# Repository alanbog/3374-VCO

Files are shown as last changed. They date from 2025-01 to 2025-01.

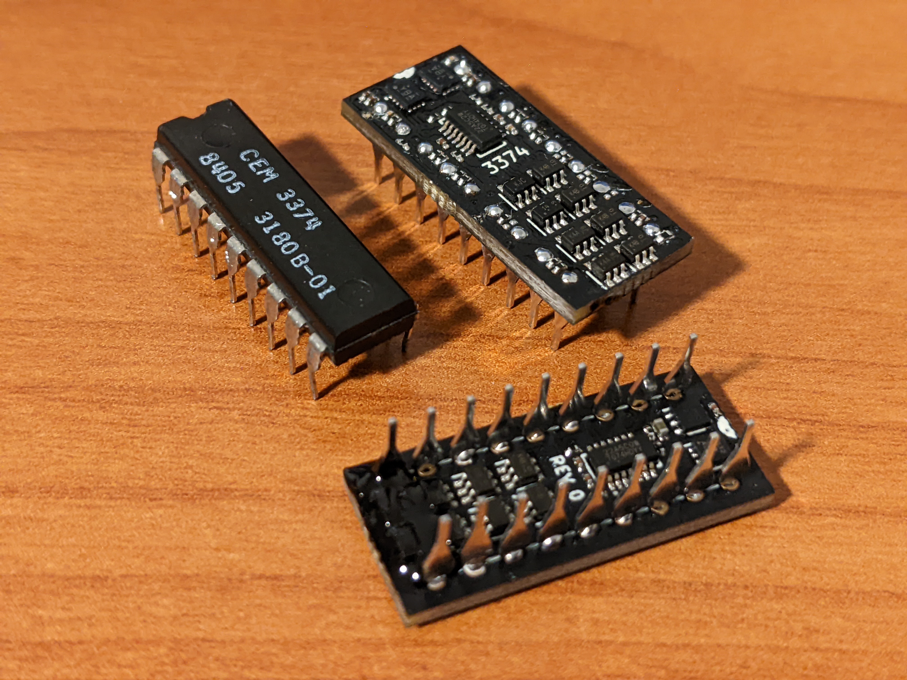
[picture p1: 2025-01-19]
3374 VCO.jpg

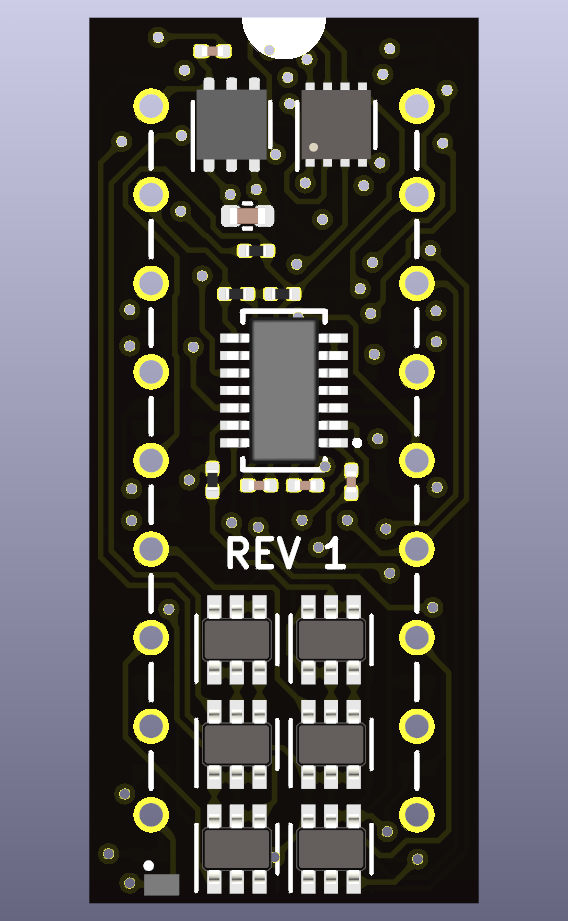
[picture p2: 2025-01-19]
Mfg Files/Drawing/Bot_3D.png

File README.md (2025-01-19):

# 3374-VCO

This repository contains a circuit designed to be a clone of the CEM 3374 VCO IC used in analog synthesizers from the early 1980s such as:

* Fender Chroma Polaris
* Oberheim Matrix 12
* Oberheim Xpander
* Akai VX600.

It is designed to operate with 12V for Vcc and -5V or -6V for Vee, which is what all of the synthesizers listed above use for supply voltages. The circuit contains two oscillator channels with triangle and sawtooth wave outputs. Triangle wave outputs have an amplitude of 1/3 Vcc, and sawtooth wave outputs have an amplitude of 2/3 Vcc. Synthesizers using the CEM 3374 that generate square/pulse waves do so with external comparator circuits. 

Channel A sync is implemented. Channel B sync is not implemented, but this feature was rarely used on the CEM 3374 (None of the synthesizers listed above use it). 

A thermistor circuit is used to provede a temperature compensated reference voltage. Typically, this voltage is used as a reference for the DAC that outputs the voltage that controls the frequency of the oscillators.

This was tested on a Chroma Polaris. It should work in all of the other synthesizers listed above, but it hasn't been tested. 

For Rev 1, the oscillator circuit was updated to fix an issue with Oberheim Synthesizers being out of tune at lower notes (although this fix hasn't yet been tested on an Oberheim synthesizer).

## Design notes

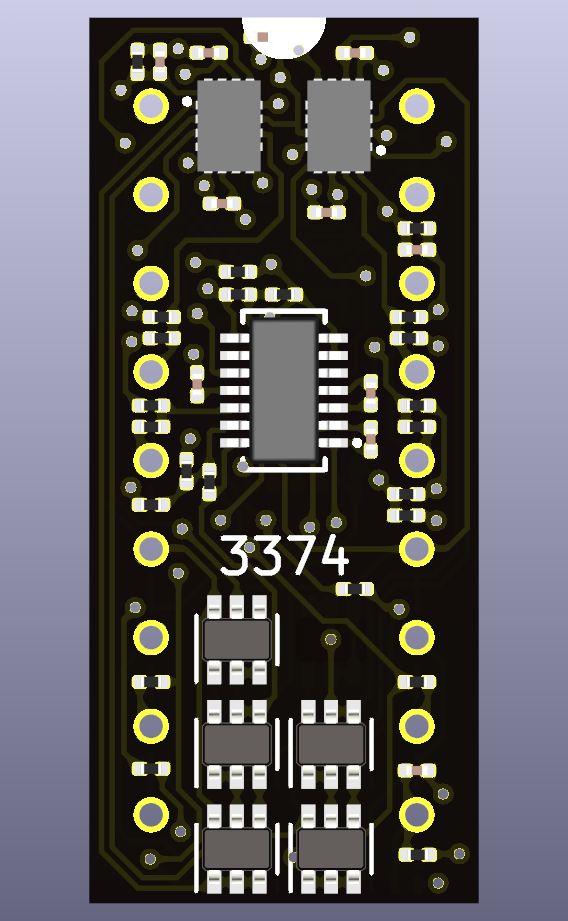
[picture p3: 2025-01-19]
Mfg Files/Drawing/Top_3D.png

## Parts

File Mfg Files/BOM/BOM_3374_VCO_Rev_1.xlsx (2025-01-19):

3374 VCO Rev 1 BOM (12-Dec-2024)
# | Reference | Qty | Value | DNP | Description | Mfg | Mfg PN | Distributor | Distributor PN | Package | Type | Substitute part okay?
1 | C1,C2,C3,C5,C6,C8,C9,C11,C12,C15,C16 | 11 | 100n |  | Capacitor, 100nF, 10%, 25V, X5R | Walsin | 0201X104K250CT | LCSC | C880779 | 201 | SMD | Yes
2 | C4,C7,C10,C14 | 4 | 680p |  | Capacitor, 680pF, 10%, 25V, X7R | Murata | GRM033R71E681KA01D | LCSC | C161490 | 201 | SMD | Yes
3 | C13 | 1 | 2.2u |  | Capacitor, 2.2uF, 10%, 25V, X5R | Murata | GRM155R61E225KE11D | LCSC | C385032 | 402 | SMD | Yes
4 | J1,J2 | 2 | FLIP PINS | DNP | Flip Pins, 9-pin | Fliptronics | FLIP-PINS-09 |  |  | FLIP-PINS-09 | DNP
5 | Q1 | 1 | MUN5314DW1 |  | Transistor, Dual Complementary Prebiased, Rb=10k, Rbe=47k | LRC | LMUN5314DW1T1G | LCSC | C417318 | SC-88 | SMD | No
6 | Q2,Q4,Q7,Q9,Q10,Q11 | 6 | DMMT3904W |  | Transistor, Dual Matched NPN | Diodes Inc | DMMT3904W-7-F | LCSC | C155305 | SC-88 | SMD | No
7 | Q3,Q5,Q6,Q8 | 4 | DMMT3906W |  | Transistor, Dual Matched PNP | Diodes Inc | DMMT3906W-7-F | LCSC | C151567 | SC-88 | SMD | No
8 | R1,R2,R20,R21 | 4 | 432K |  | Resistor, 432k Ohm, 1%, 0.05W | Walsin | WR02X4323FAL | LCSC | C367623 | 201 | SMD | Yes
9 | R3,R24 | 2 | 365 |  | Resistor, 365 Ohm, 1%, 0.05W | Uniroyal | 0201WMF3650TEE | LCSC | C423558 | 201 | SMD | Yes
10 | R4,R5,R6,R9,R10,R11,R12,R13,R17,R18,R19,R22,R25,R26 | 14 | 10k |  | Resistor, 10k Ohm, 1%, 0.05W | Uniroyal | 0201WMF1002TEE | LCSC | C473048 | 201 | SMD | Yes
11 | R7,R8,R14,R16 | 4 | 4.99k |  | Resistor, 4.99k Ohm, 1%, 0.05W | Uniroyal | 0201WMF4991TEE | LCSC | C473528 | 201 | SMD | Yes
12 | R15,R27 | 2 | 3.32k |  | Resistor, 3.32k Ohm, 1%, 0.05W | Uniroyal | 0201WMF3321TEE | LCSC | C474121 | 201 | SMD | Yes
13 | R23 | 1 | 11.8k |  | Resistor, 11.8k Ohm, 1%, 0.05W | Yageo | AC0201FR-0711K8L | LCSC | C910595 | 201 | SMD | Yes
14 | U1,U2 | 2 | DG4053E |  | Triple SPDT CMOS Analog Switch | Vishay | DG4053EEN-T1-GE4 | Mouser | 78-DG4053EEN-T1-GE4 | 16-miniQFN | SMD | No
15 | U3,U6 | 2 | TL074H |  | IC, Quad Op Amp | Texas Instruments | TL074HIDYYR | Mouser | 595-TL074HIDYYR | 14-SOT-23-THIN | SMD | No
16 | U4 | 1 | AP7370-50FDC |  | IC, LDO, 5V | Diodes Inc | AP7370-50FDC-7 | Mouser | 621-AP7370-50FDC-7 | 6-UDFN | SMD | No
17 | U5 | 1 | TLV9032 |  | IC, Dual Comparator | Texas Instruments | TLV9032DSGR | Mouser | 595-TLV9032DSGR | 8-WSON | SMD | No
18 | U7 | 1 | TMP6131DECR |  | IC, 10k PTC Thermistor | Texas Instruments | TMP6131DECR | LCSC | C2870682 | 2-X1SON | SMD | No
 | Notes:
 | DNP = Do Not Populate.
 | The distributor indicated in the BOM is a suggestion. Any authorized distibutor may be used.

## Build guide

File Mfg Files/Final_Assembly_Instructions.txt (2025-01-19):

These are instructions to turn the PCB assemblies into the final product.

1.  If the PCBAs are panelized, depanelize them, and sand any remaining mouse bites or rough edges.

2.  Solder the Flip-Pins. I recommend using 20-pin Flip-Pins. Two sets of 20-pin Flip-Pins can be used for every two boards.
    Insert the Flip-Pins in the bottom of the board. Make sure that the plastic aligner does not overlap the thermistor (U7). 
    Follow instructions here:
    http://oshchip.org/products/Soldering_Flip-Pins.html
    Archived: https://web.archive.org/web/20231003143201/http://oshchip.org/products/Soldering_Flip-Pins.html
    I found that it was best to use a flux pen and thin solder (0.015" diameter).

    Note: It looks like flip pins have been discontinued, so I have been using TE Connectivity 1544210-2 as an alternative. It requires some cutting and bending to get it in the right shape. 

3.  Clean flux off of the boards. I used isopropyl alcohol and an ESD-safe brush. 

4.  Add a blob of MG Chemicals 8349TFM that completely encapsulates U7, Q14, and Q15. These components are on the bottom of the board opposite from the pin 1 marking. Let cure for at least 16 hours.

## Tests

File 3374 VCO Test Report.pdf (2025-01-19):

# 3374 VCO Test Report

Alan Boguslawski

Rev 1

18-Jan-25

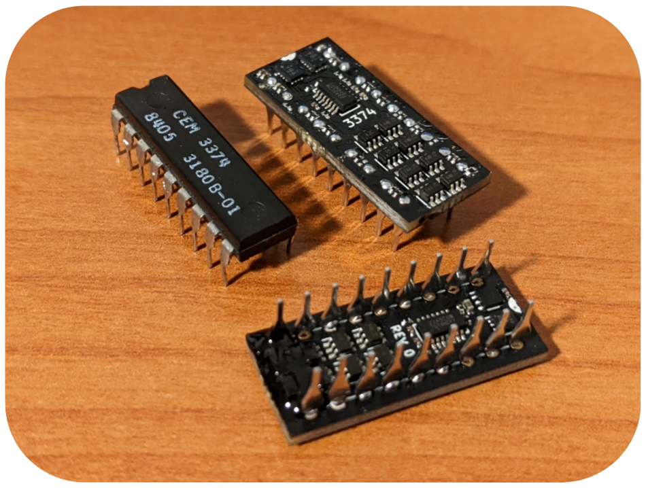
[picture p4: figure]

3374 VCO Test Report | 2

### 1. Background

The purpose of these tests is to verify the functionality of the 3374 VCO clone PCB and to compare the performance to an original CEM 3374 IC. All tests were conducted using a Fender Chroma Polaris running firmware version 8, but the performance characteristics should be similar for other synthesizers using the CEM 3374. The Chroma Polaris supplies the 3374 with 12V and -5V. The Oberheim Matrix 12 and Xpander use the same supply voltages, so performance is expected to be the same. The Akai VX600 also has a 12V positive supply, but the negative supply is -6V (which is unlikely to affect performance).

Revision 1 of this board has modified oscillators, so tests relating to the frequency or wave shape have been retested.

### 2. Frequency vs Voltage

Revision Tested: 1

The frequency and voltage was measured for both oscillators in a CEM 3374 and a clone at increments of one octave. The voltage was measured at the output of the DAC before the voltage divider going to the VCO’s input. The actual voltage at the VCO’s input will be around 1/28th of this voltage. The results are plotted below with a logarithmic vertical axis. Synthesizers using these VCOs use digital calibration, so it is not necessary for the curve to be exactly the same, but it should be close.

3374 VCO Test Report | 3

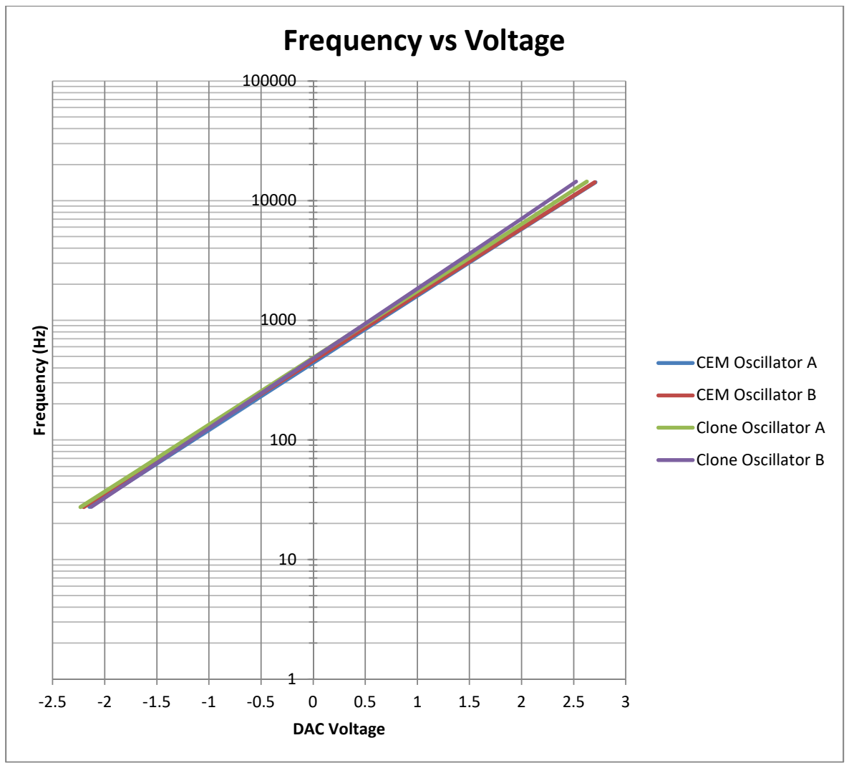
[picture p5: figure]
3 Frequency ⁽Hz⁾; DAC Voltage; Frequency vs Voltage; CEM Oscillator A; CEM Oscillator B; Clone Oscillator A; Clone Oscillator B

### 3. Frequency Drift

Revision Tested: 0

After automatic calibration, the frequency of several notes was measured on both oscillators of the CEM 3374 and the clone. After one hour, the frequency was measured again without recalibrating first. The temperature in the synthesizer’s enclosure near the VCOs was 20°C measured by a thermocouple at the beginning of the test, and although it was expected that the temperature would rise, it was still 20°C at the end.

3374 VCO Test Report | 4
| Note | CEM A | CEM B | Clone A | Clone B
Initial | 110Hz (A2) | 110.7 | 110.6 | 110.6 | 110.4
| 440Hz (A4) | 442.3 | 442.4 | 442.4 | 442.3
| 1760Hz (A6) | 1768 | 1769 | 1770 | 1769
After 1 hour | 110Hz (A2) | 111.1 | 111.1 | 111.5 | 111.2
| 440Hz (A4) | 444.1 | 444.1 | 444.7 | 444.2
| 1760Hz (A6) | 1775 | 1776 | 1779 | 1775

Both the CEM 3374 and the clone’s frequencies drifted slightly higher by around the same amount. This is likely due to the supply voltages drifting slightly as the power supply heated up and not the VCOs themselves.

### 4. Temperature Compensation Output

Revision Tested: 0

The VCOs contain a temperature compensated voltage output that is intended to be used as a reference voltage for the DAC that controls the frequency. The voltage should ideally have a temperature coefficient of 1/T where T is the temperature in Kelvin. This is around 3400ppm/°C when near room temperature. In the case of the clone VCO, this voltage is generated from a thermistor circuit that is bonded to the transistors used in the exponential converter with thermally conductive epoxy. As I don’t have equipment to accurately characterize the voltage output at different temperatures, the voltage was measured only at 20°C. This exact voltage is not too important other than to verify that it works.

VCO | VTC output voltage at 20°C
CEM 3374 Rev 0 | 2.47V
Clone | 2.30V

### 5. Waveform Outputs

Revision Tested: 1

The sawtooth and triangle wave outputs were captured on an oscilloscope at multiple frequencies in two-octave increments. The CEM 3374 and the clone produce similar results, but with a couple minor differences:

1. The clone restarts each cycle faster when the triangle wave falls below 0V. This means that the CEM 3374 has a slightly larger portion of the triangle wave below 0V. This should not affect the timbre of the sound.
2. The CEM 3374 has small negative spikes after the falling edge of the sawtooth waves that the clone does not have. Almost all of the harmonics added from these spikes will be above the human hearing range. The filters and amplifiers in the synthesizer should eliminate them, so the difference to the sound is negligible.

3374 VCO Test Report | 5

There does not appear to be a large difference in the waveform shape between low frequencies and high frequencies in both the CEM 3374 and the clone.

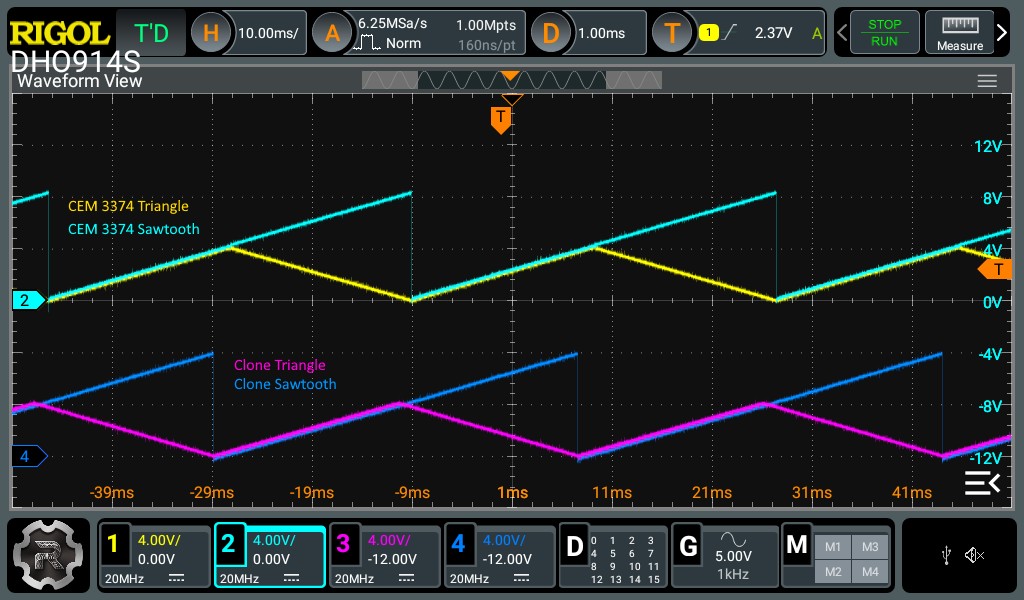
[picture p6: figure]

Figure 1 - Waveforms at 27.5Hz (A0)

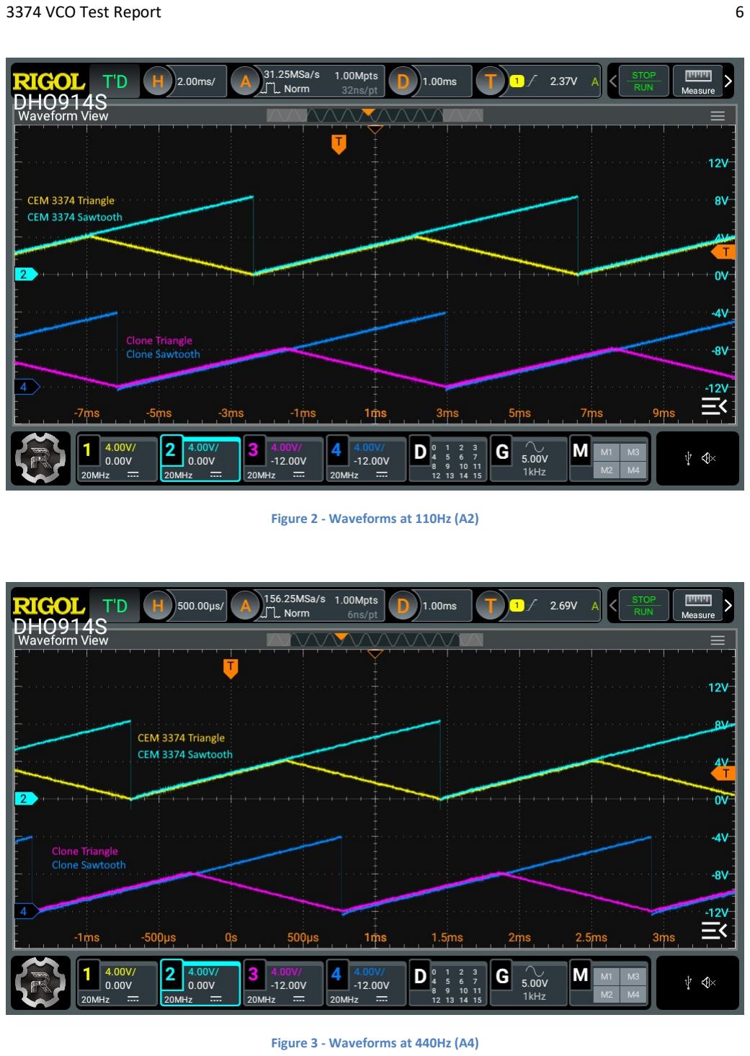
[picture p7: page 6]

3374 VCO Test Report | 6

Figure 2 - Waveforms at 110Hz (A2)

Figure 3 - Waveforms at 440Hz (A4)

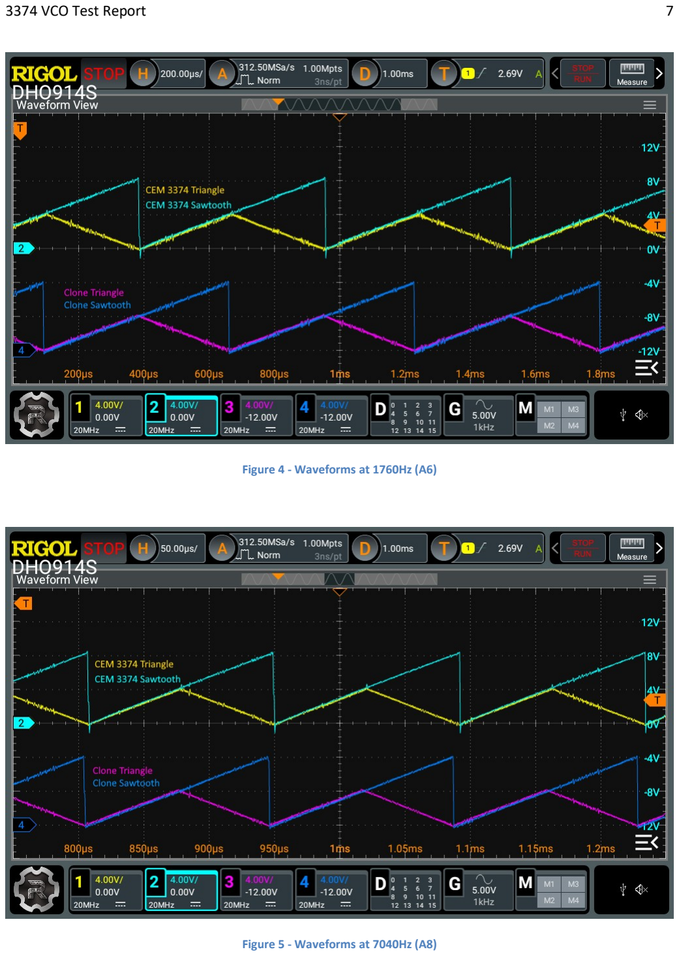
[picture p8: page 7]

3374 VCO Test Report | 7

Figure 4 - Waveforms at 1760Hz (A6)

Figure 5 - Waveforms at 7040Hz (A8)

3374 VCO Test Report | 8

### 6. Sync Input

Revision Tested: 0

Oscillator A of the VCOs contains a sync input that causes the waveform cycle to reset when it is pulled low. In a typical synthesizer design, it can be configured to be connected to the sawtooth output of oscillator B through a capacitor so that the frequency of oscillator A is synced to oscillator B.

In these tests, the sawtooth outputs from both oscillators of the CEM 3374 and rev 0 clone were captured with an oscilloscope with sync enabled while both VCOs played similar notes (one semitone apart).

When the sync occurred in the first half of channel A’s cycle, the outputs of the CEM 3374 and the clone look almost identical.

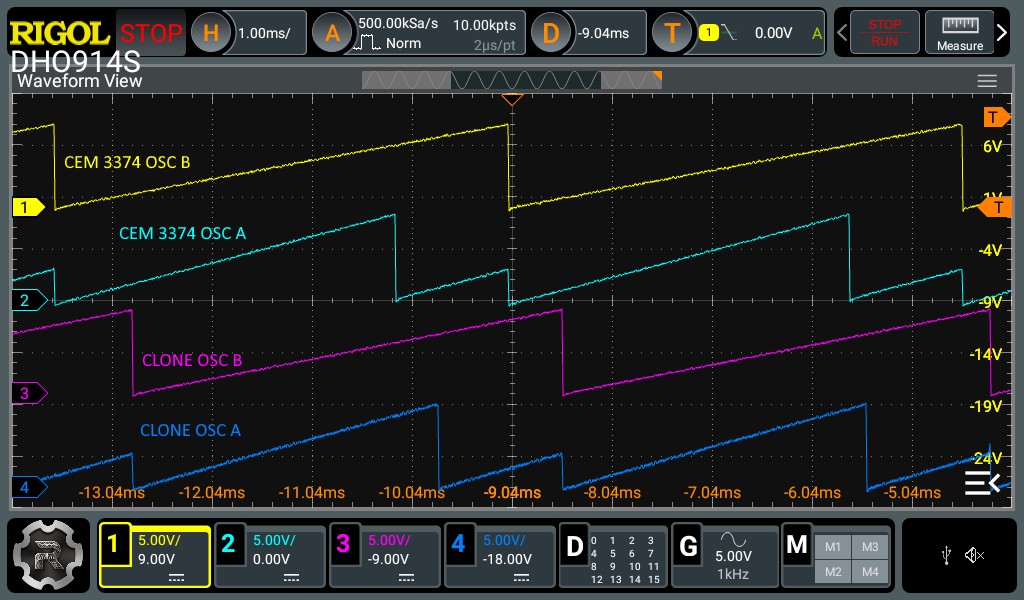
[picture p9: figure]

Figure 6 - Sawtooth outputs with sync enabled, sync in first half of wave
When the sync occurred in the second half of channel A’s cycle, there was a brief pulse to 8V before the sawtooth wave restarted at 0V. In the CEM 3374, this pulse was just a couple of microseconds, which was short enough that it didn’t always show up on the oscilloscope at the zoom level shown. In the clone, the pulse lasted around 12µs. These pulses are caused by the triangle-to-sawtooth converters that invert the falling portion of the triangle wave to form the second half of the sawtooth waves. When the sync input causes the capacitor to discharge, there is a short delay before the triangle-to-sawtooth converter detects that it should stop inverting the signal.

3374 VCO Test Report | 9

The pulses caused from this sync feature appear to be one of the biggest differences in the output waveforms of the CEM 3374 and the clone, but in reality, this difference is still negligible. The sounds produced from these spikes are almost entirely outside of the human hearing range, and they will most likely be eliminated by the time the signal makes it though the synthesizer’s filters and amplifiers. For example, a screenshot of a recording in Ableton Live of the same note played on the clone is shown in Figure 8. The synthesizer’s filter cutoff frequency was turned up all the way during the recording.

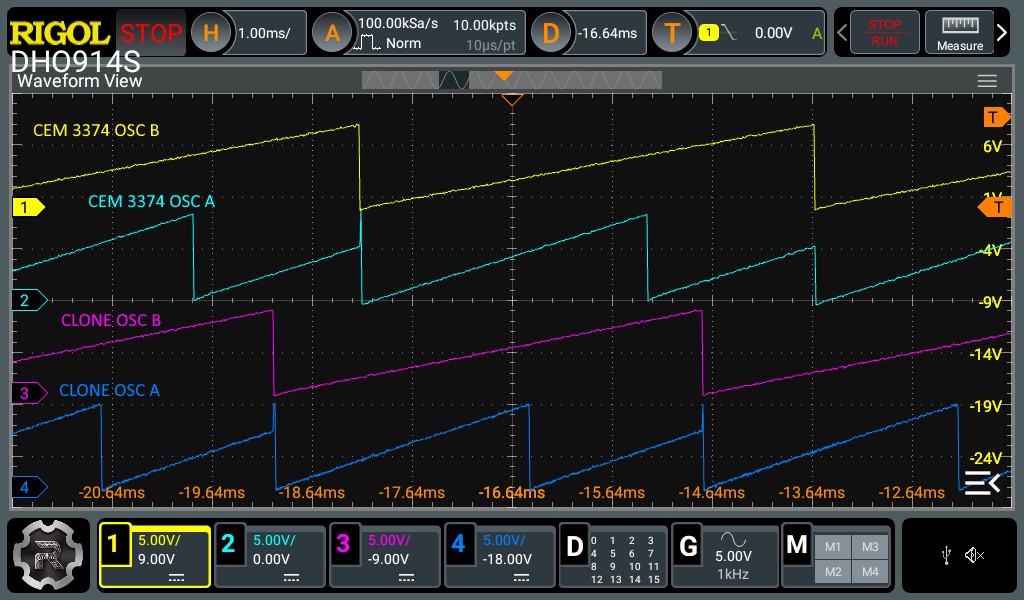
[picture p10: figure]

Figure 7 - Sawtooth outputs with sync enabled, sync in second half of wave

Figure 8 - Screenshot from Ableton Live of a recording of the same waveform from oscillator A of the clone VCO

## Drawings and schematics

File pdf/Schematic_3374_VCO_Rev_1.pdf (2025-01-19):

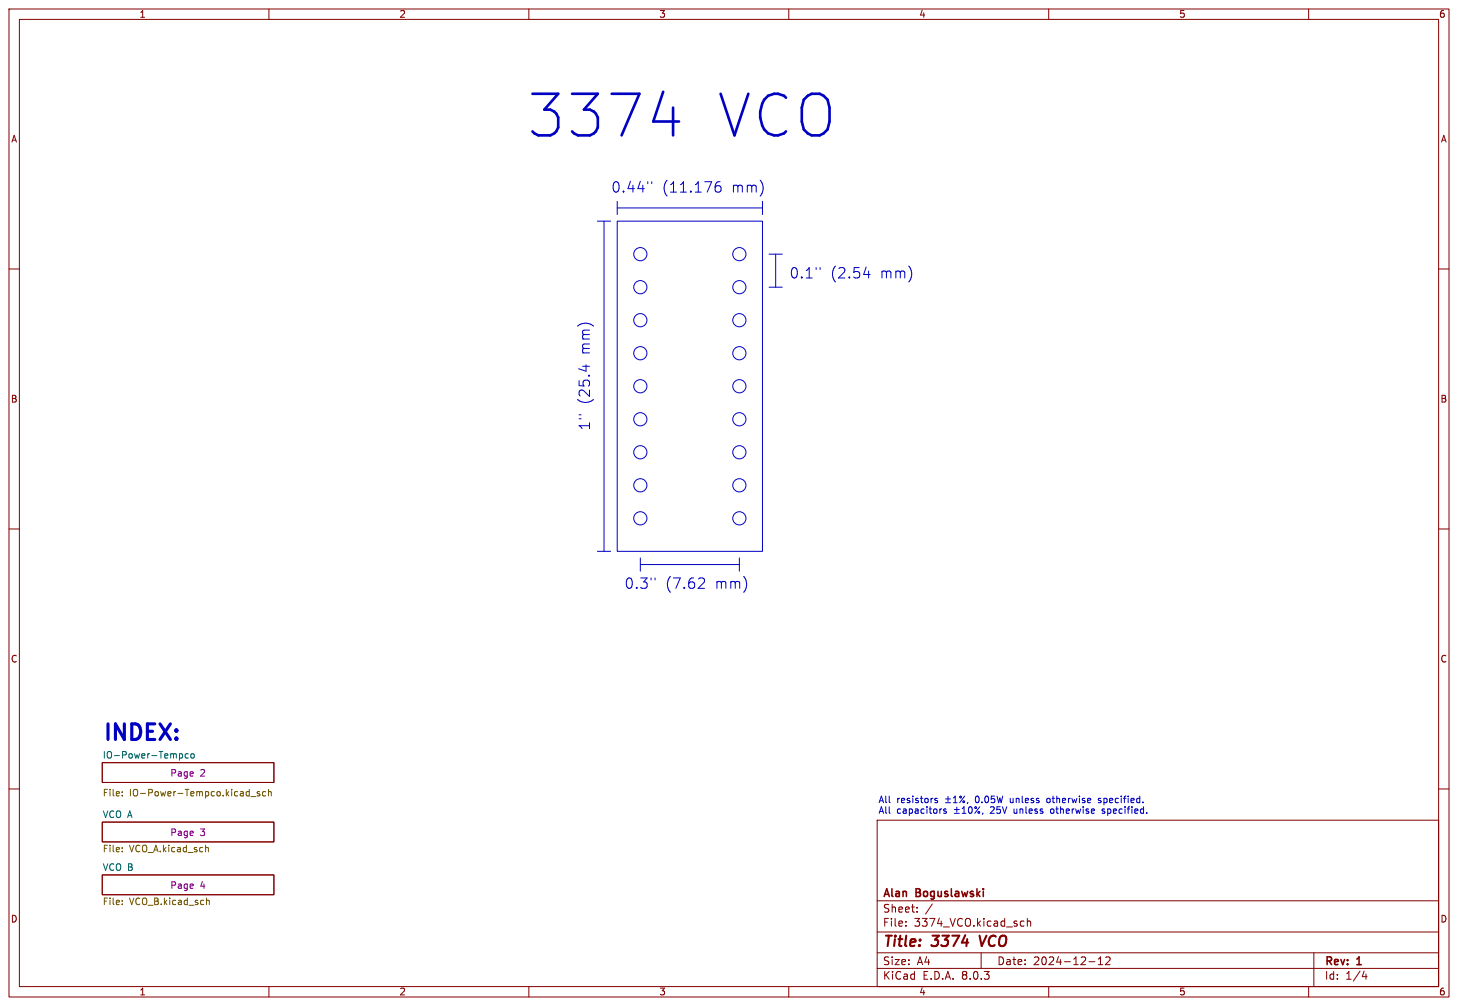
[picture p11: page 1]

IO-Power-Tempco File: IO-Power-Tempco.kicad_sch

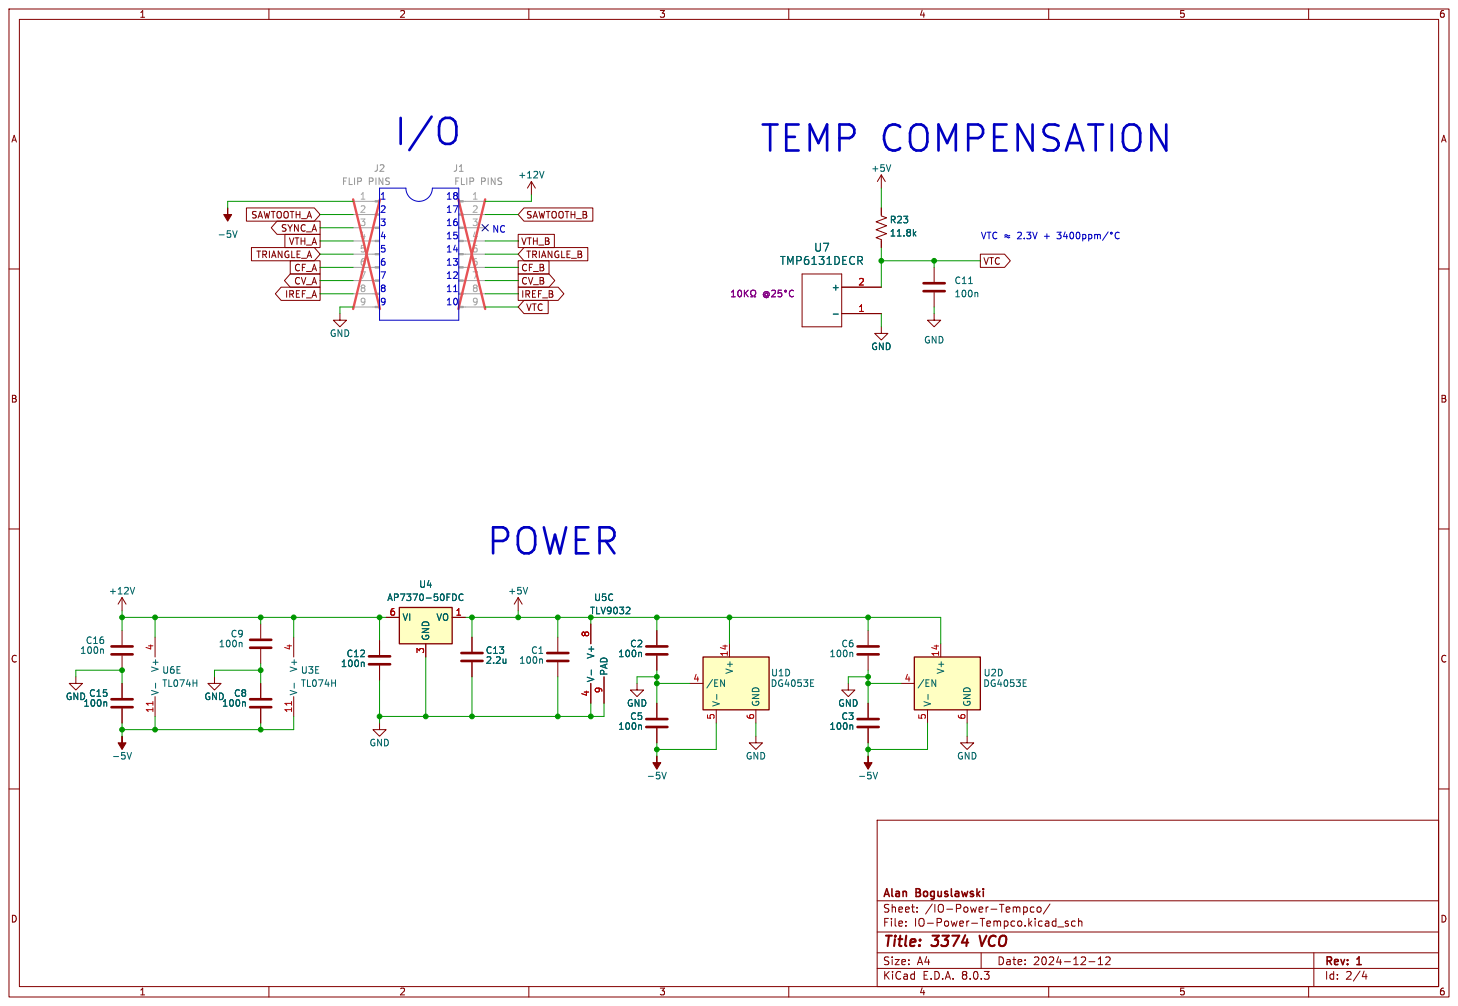
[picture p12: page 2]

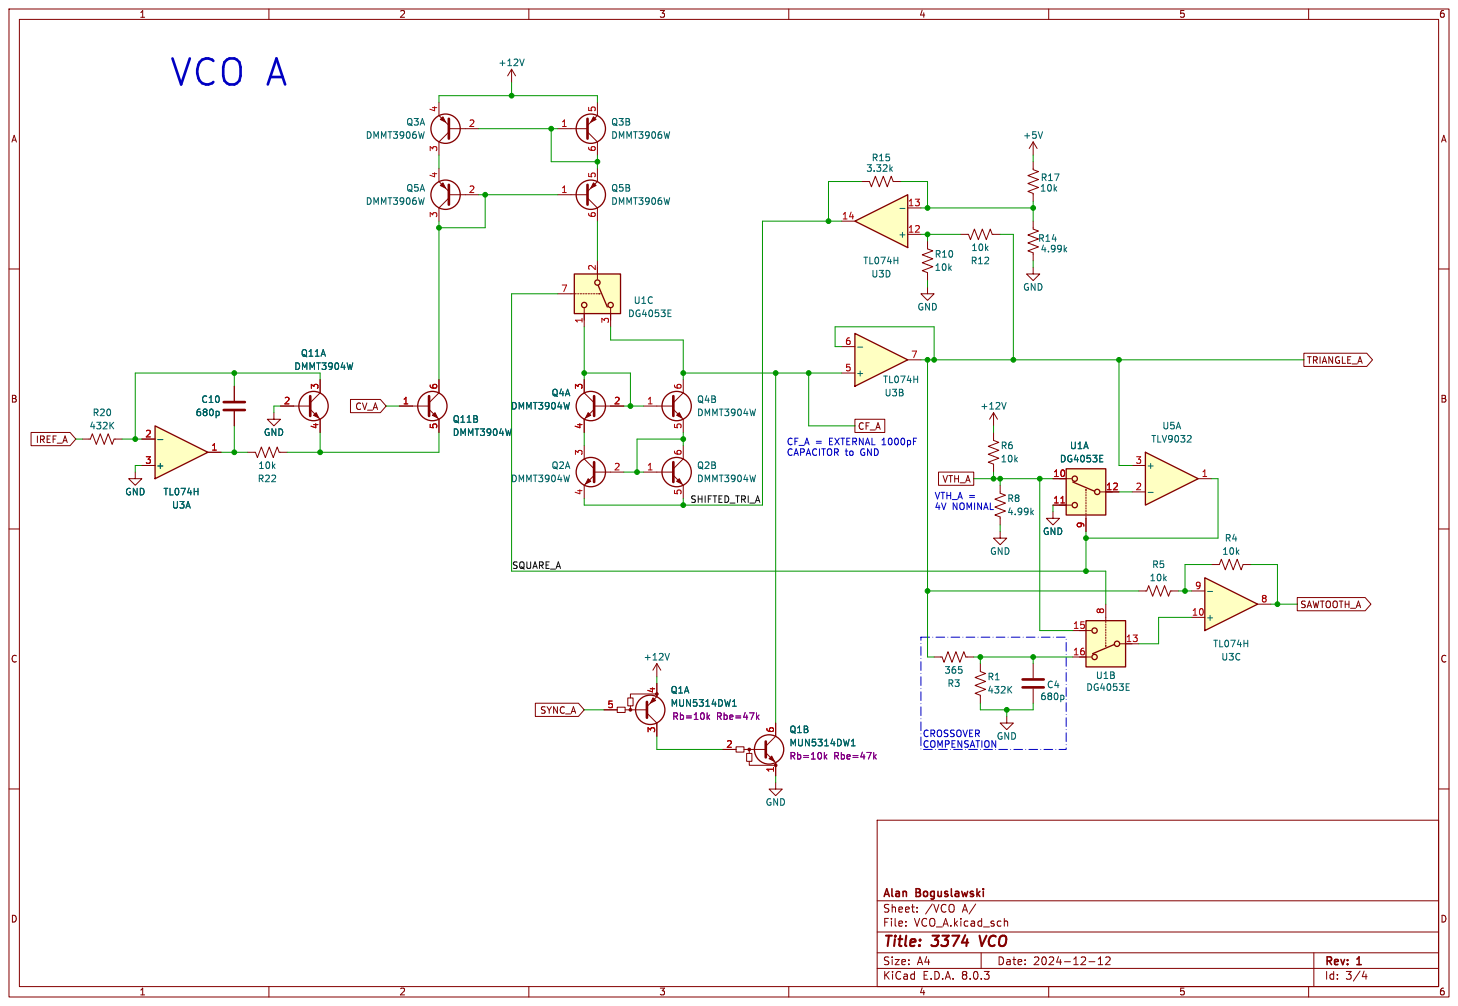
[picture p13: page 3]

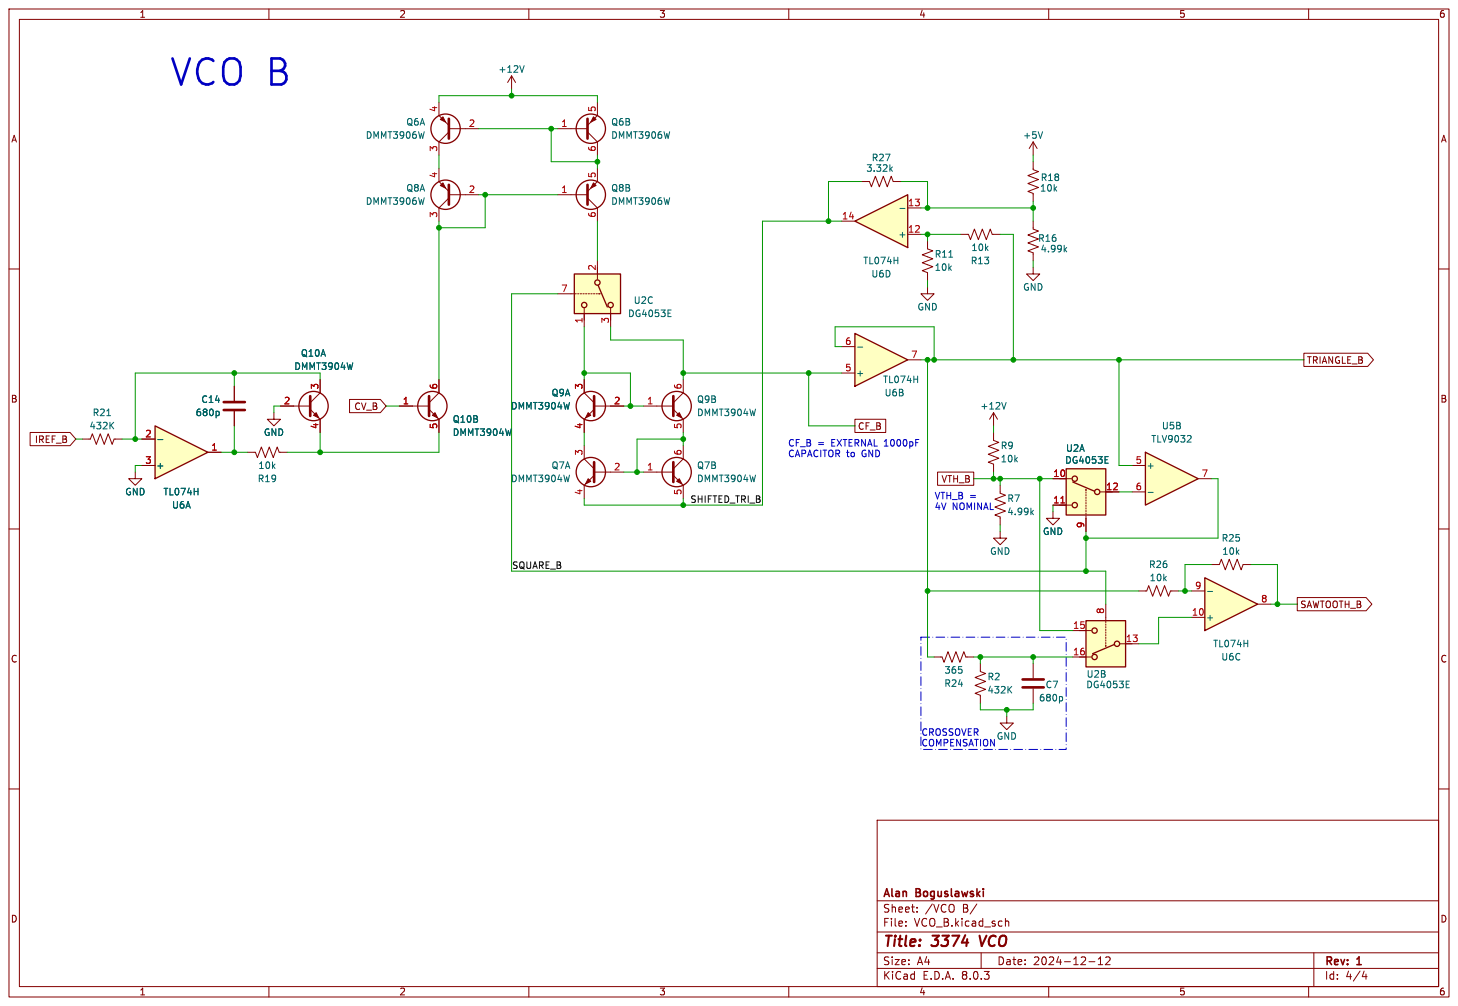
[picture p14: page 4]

CF_B = EXTERNAL 1000pF CAPACITOR to GND

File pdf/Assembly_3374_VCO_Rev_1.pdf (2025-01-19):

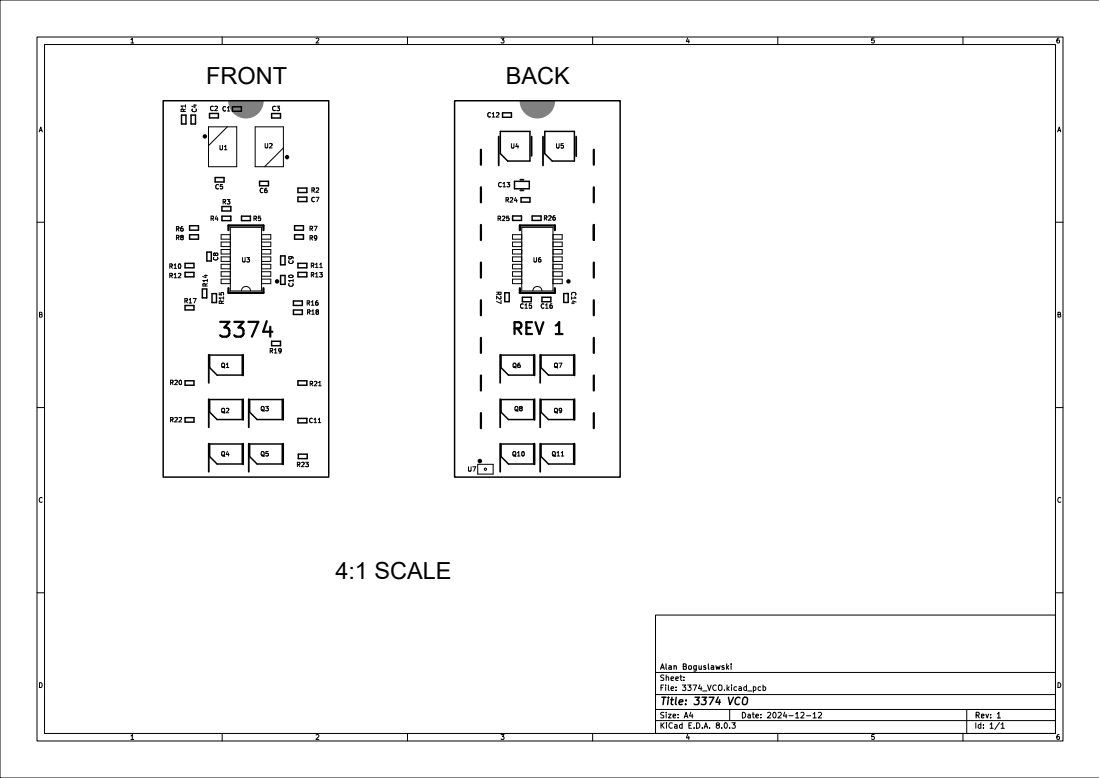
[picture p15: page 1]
FRONT; BACK; 4:1 SCALE

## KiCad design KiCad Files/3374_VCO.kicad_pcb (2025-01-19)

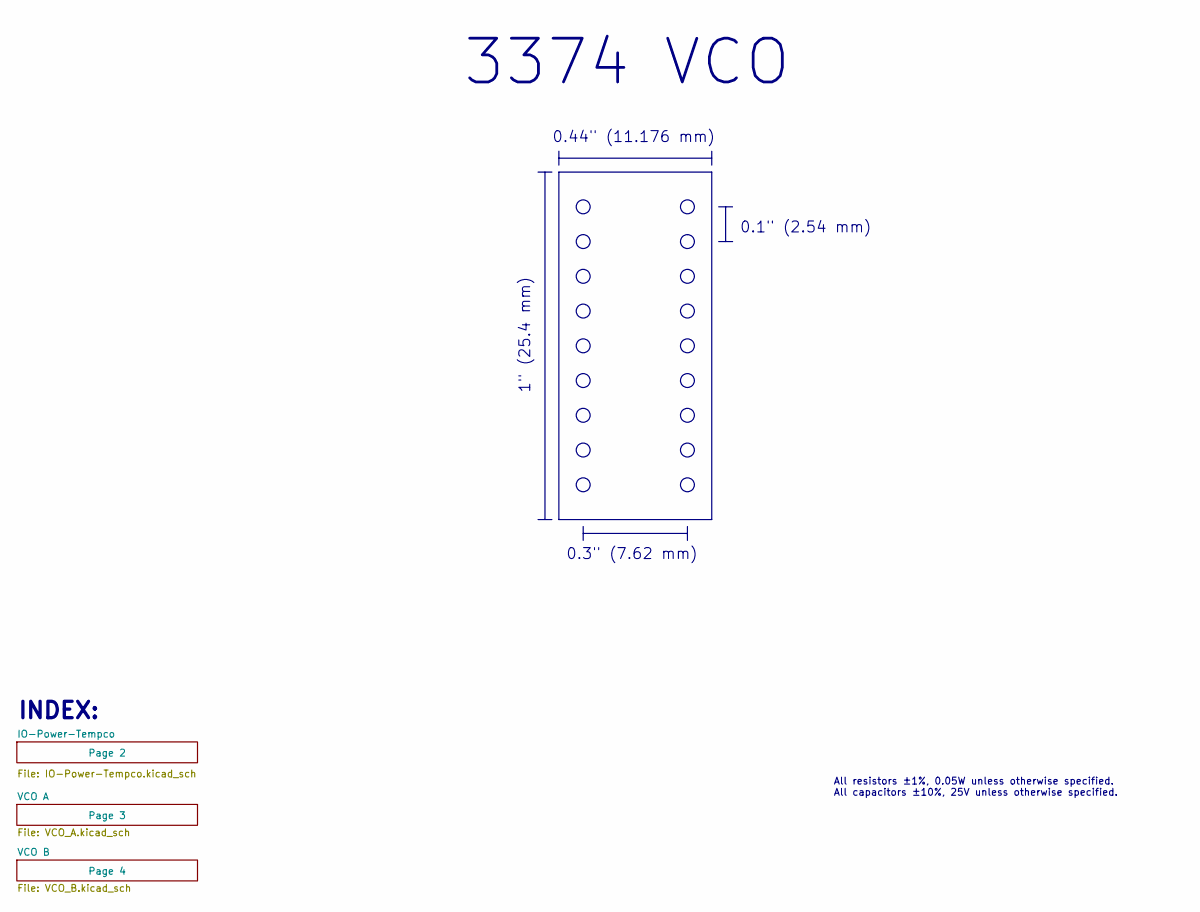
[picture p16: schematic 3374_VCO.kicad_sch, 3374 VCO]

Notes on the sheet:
INDEX:
0.3" (7.62 mm)
All resistors ±1%, 0.05W unless otherwise specified. All capacitors ±10%, 25V unless otherwise specified.
0.44" (11.176 mm)
3374 VCO
1" (25.4 mm)
0.1" (2.54 mm)

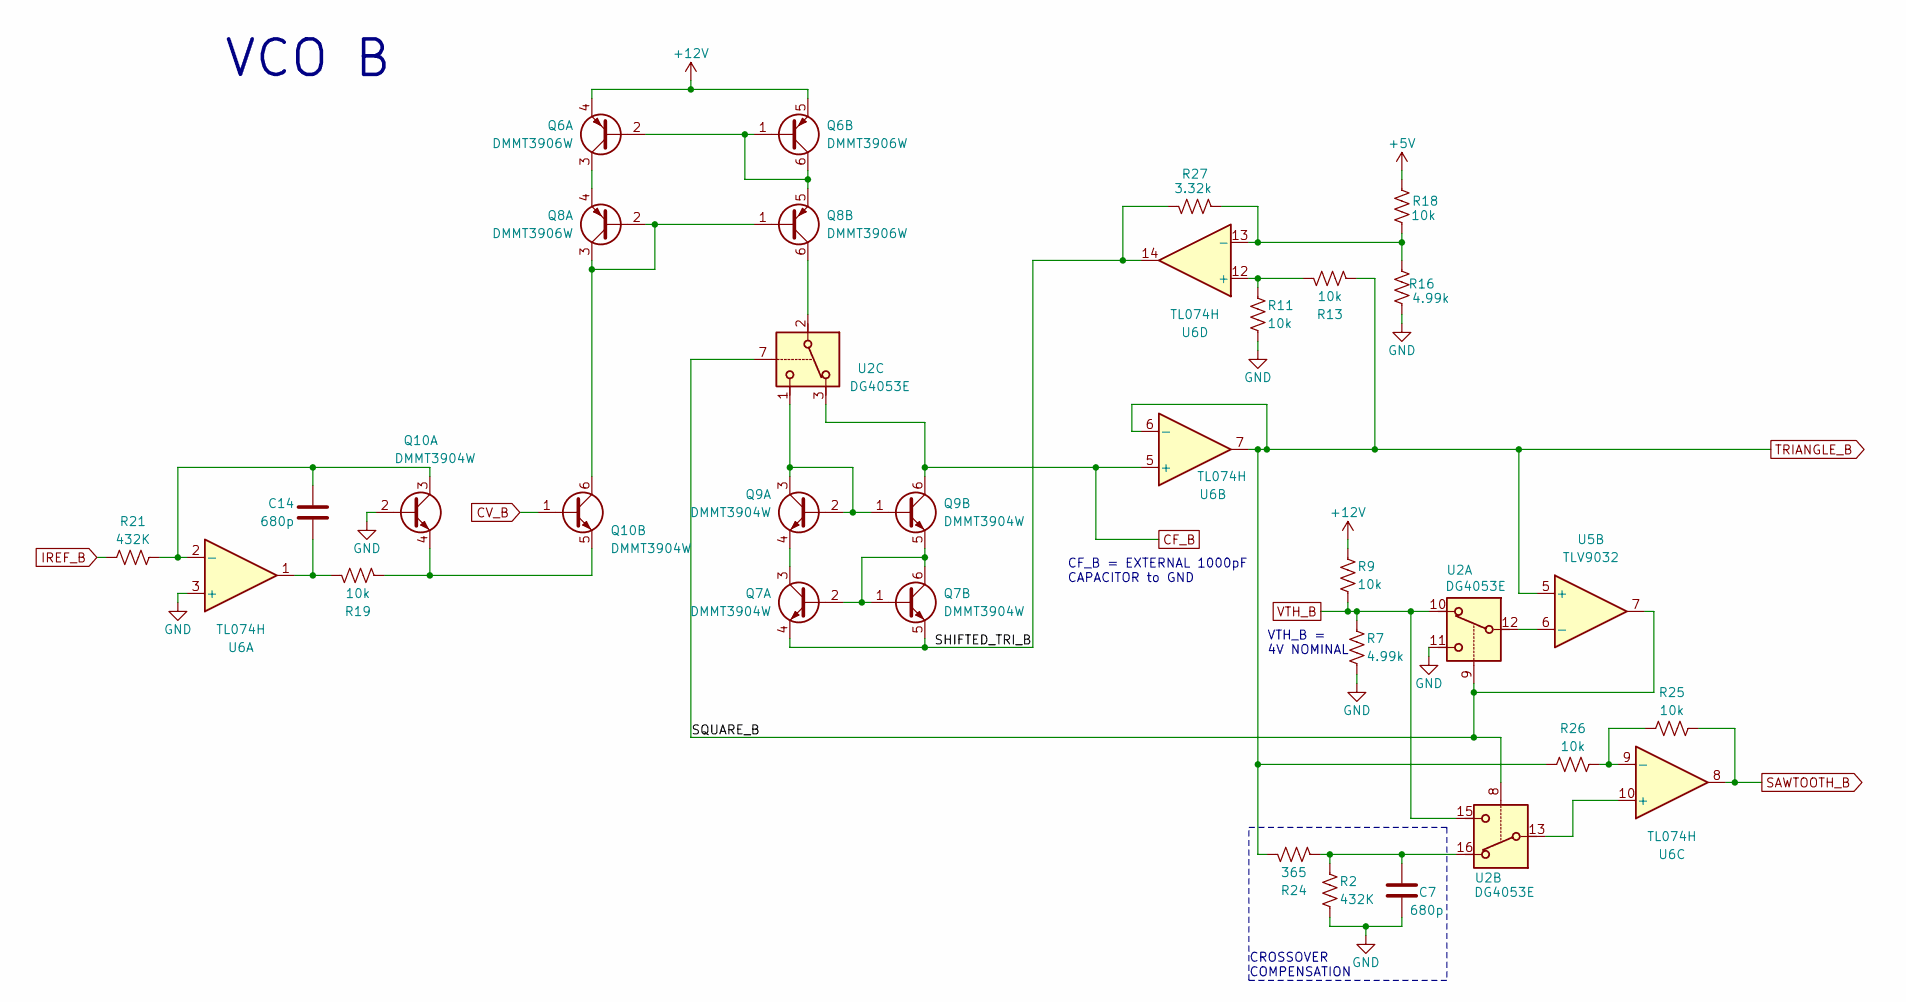
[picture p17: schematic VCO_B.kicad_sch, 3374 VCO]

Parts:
C7, C14: 680p; C_0201_0603Metric; Rating 25V; Tolerance 10%; Mfg PN GRM033R71E681KA01D
Q6, Q8: DMMT3906W; SOT-363_SC-70-6; Mfg PN DMMT3906W-7-F
Q7, Q9, Q10: DMMT3904W; SOT-363_SC-70-6; Mfg PN DMMT3904W-7-F
R2, R21: 432K; R_0201_0603Metric; Rating 0.05W; Tolerance 1%; Mfg PN WR02X4323FAL
R7, R16: 4.99k; R_0201_0603Metric; Rating 0.05W; Tolerance 1%; Mfg PN 0201WMF4991TEE
R9, R11, R13, R18, R19, R25, R26: 10k; R_0201_0603Metric; Rating 0.05W; Tolerance 1%; Mfg PN 0201WMF1002TEE
R24: 365; R_0201_0603Metric; Rating 0.05W; Tolerance 1%; Mfg PN 0201WMF3650TEE
R27: 3.32k; R_0201_0603Metric; Rating 0.05W; Tolerance 1%; Mfg PN 0201WMF3321TEE
U2: DG4053E; QFN_EEN-T1-GE4_VIS; Mfg PN DG4053EEN-T1-GE4
U5: TLV9032; WSON-8-1EP_2x2mm_P0.5mm_EP0.9x1.6mm; Mfg PN TLV9032DSGR
U6: TL074H; SOT23_DYY_TEX-L; Mfg PN TL074HIDYYR

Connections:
+5V: R18.2; also elsewhere on the board
+12V: Q6.4 (E1), Q6.5 (E2), R9.1; also elsewhere on the board
/VCO B/SHIFTED_TRI_B: Q7.4 (E1), Q7.5 (E2), R27.1, U6.14
/VCO B/SQUARE_B: U2.7, U2.8, U2.9, U5.7
CF_B: Q9.6 (C2), U2.3, U6.5 (+); also elsewhere on the board
CV_B: Q10.1 (B2); also elsewhere on the board
GND: C7.2, Q10.2 (B1), R2.2, R7.2, R11.2, R16.2, U2.11, U6.3 (+); also elsewhere on the board
IREF_B: R21.1; also elsewhere on the board
unnamed: C7.1, R2.1, R24.2, U2.16
unnamed: C14.2, R19.1, U6.1
unnamed: Q6.1 (B2), Q6.2 (B1), Q6.6 (C2), Q8.5 (E2)
unnamed: Q6.3 (C1), Q8.4 (E1)
unnamed: Q7.1 (B2), Q7.2 (B1), Q7.6 (C2), Q9.5 (E2)
unnamed: Q7.3 (C1), Q9.4 (E1)
unnamed: Q8.6 (C2), U2.2
unnamed: Q9.1 (B2), Q9.2 (B1), Q9.3 (C1), U2.1
unnamed: C14.1, Q10.3 (C1), R21.2, U6.2 (-)
unnamed: Q10.4 (E1), Q10.5 (E2), R19.2
unnamed: Q8.1 (B2), Q8.2 (B1), Q8.3 (C1), Q10.6 (C2)
unnamed: U2.12, U5.6 (-)
unnamed: U2.13, U6.10 (+)
unnamed: R25.1, R26.2, U6.9 (-)
unnamed: R11.1, R13.1, U6.12 (+)
unnamed: R16.1, R18.1, R27.2, U6.13 (-)
SAWTOOTH_B: R25.2, U6.8; also elsewhere on the board
TRIANGLE_B: R13.2, R24.1, R26.1, U5.5 (+), U6.6 (-), U6.7; also elsewhere on the board
VTH_B: R7.1, R9.2, U2.10, U2.15; also elsewhere on the board

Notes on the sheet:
CROSSOVER COMPENSATION
VCO B
VTH_B = 4V NOMINAL
CF_B = EXTERNAL 1000pF CAPACITOR to GND

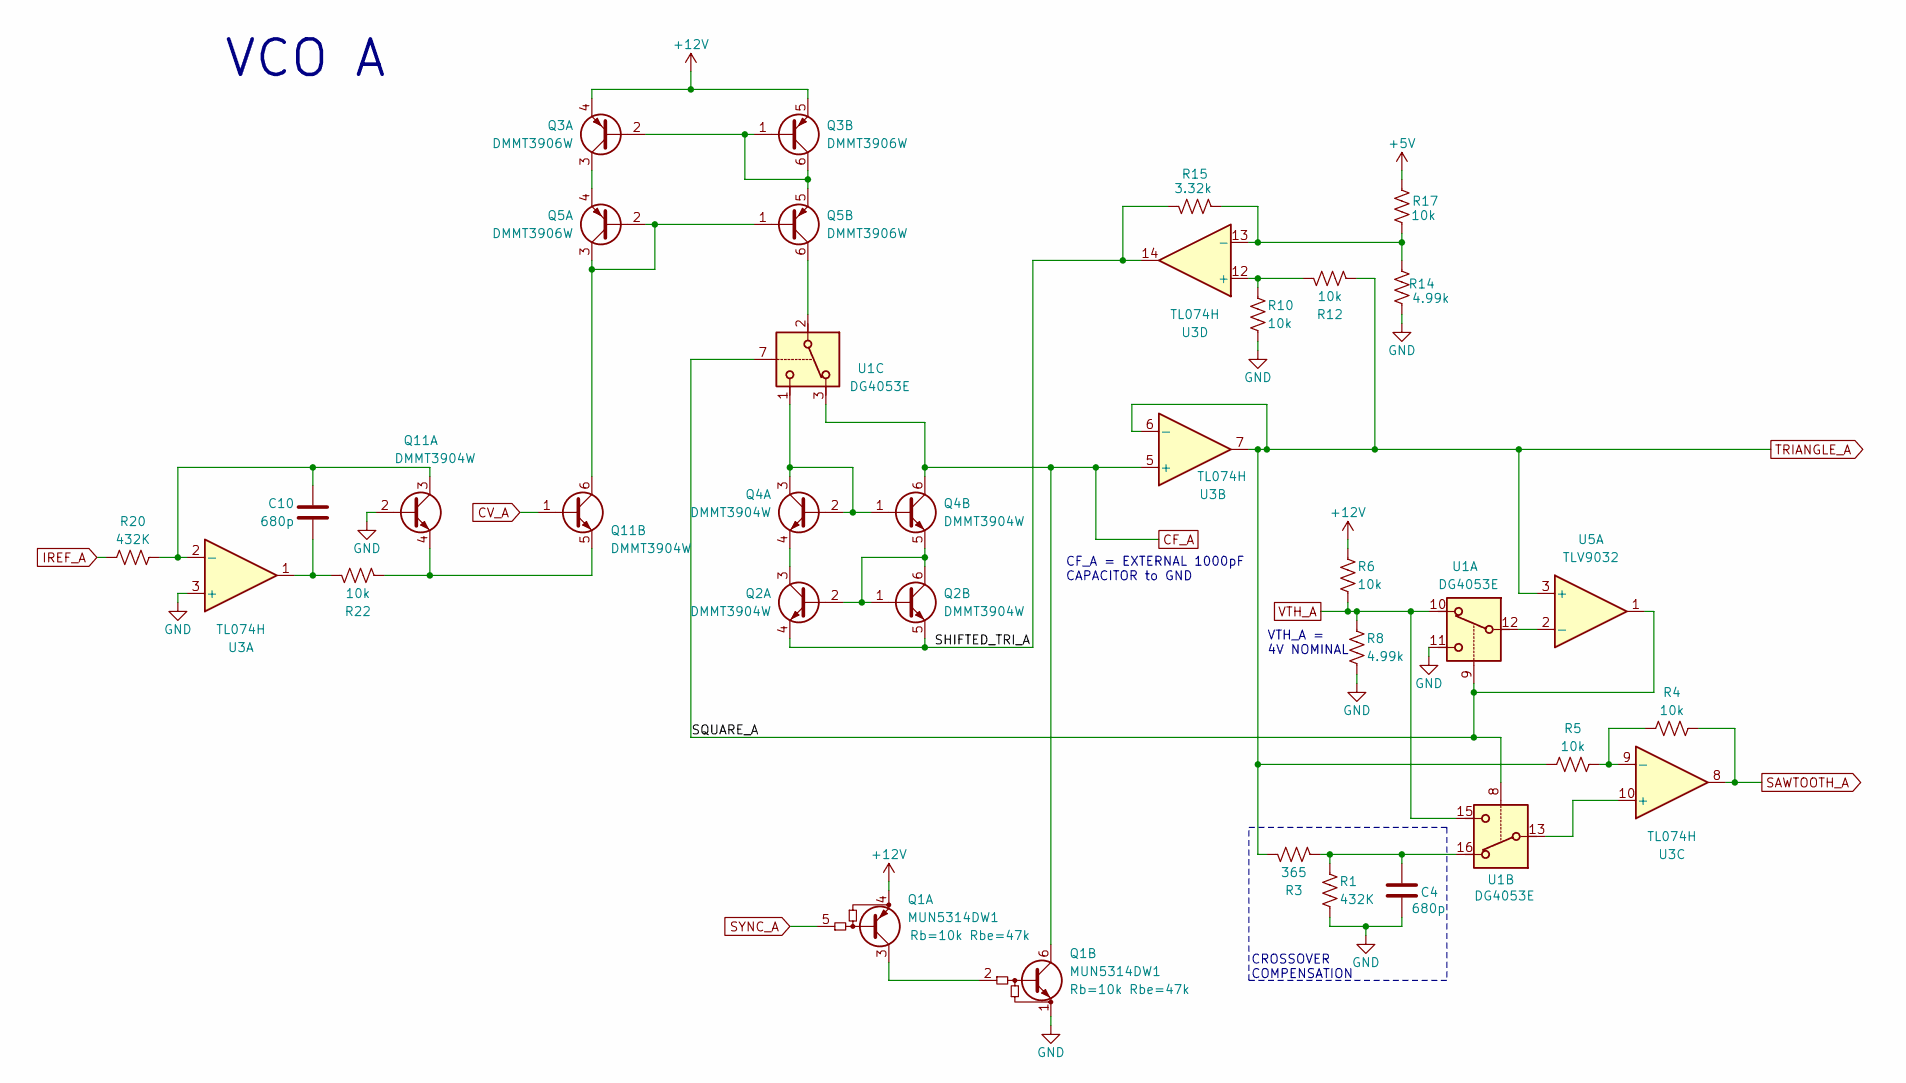
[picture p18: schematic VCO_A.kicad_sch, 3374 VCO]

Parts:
C4, C10: 680p; C_0201_0603Metric; Rating 25V; Tolerance 10%; Mfg PN GRM033R71E681KA01D
Q1: MUN5314DW1; SOT-363_SC-70-6; Mfg PN LMUN5314DW1T1G
Q2, Q4, Q11: DMMT3904W; SOT-363_SC-70-6; Mfg PN DMMT3904W-7-F
Q3, Q5: DMMT3906W; SOT-363_SC-70-6; Mfg PN DMMT3906W-7-F
R1, R20: 432K; R_0201_0603Metric; Rating 0.05W; Tolerance 1%; Mfg PN WR02X4323FAL
R3: 365; R_0201_0603Metric; Rating 0.05W; Tolerance 1%; Mfg PN 0201WMF3650TEE
R4, R5, R6, R10, R12, R17, R22: 10k; R_0201_0603Metric; Rating 0.05W; Tolerance 1%; Mfg PN 0201WMF1002TEE
R8, R14: 4.99k; R_0201_0603Metric; Rating 0.05W; Tolerance 1%; Mfg PN 0201WMF4991TEE
R15: 3.32k; R_0201_0603Metric; Rating 0.05W; Tolerance 1%; Mfg PN 0201WMF3321TEE
U1: DG4053E; QFN_EEN-T1-GE4_VIS; Mfg PN DG4053EEN-T1-GE4
U3: TL074H; SOT23_DYY_TEX-L; Mfg PN TL074HIDYYR
U5: TLV9032; WSON-8-1EP_2x2mm_P0.5mm_EP0.9x1.6mm; Mfg PN TLV9032DSGR

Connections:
+5V: R17.2; also elsewhere on the board
+12V: Q1.4 (E1), Q3.4 (E1), Q3.5 (E2), R6.1; also elsewhere on the board
/VCO A/SHIFTED_TRI_A: Q2.4 (E1), Q2.5 (E2), R15.1, U3.14
/VCO A/SQUARE_A: U1.7, U1.8, U1.9, U5.1
CF_A: Q1.6 (C2), Q4.6 (C2), U1.3, U3.5 (+); also elsewhere on the board
CV_A: Q11.1 (B2); also elsewhere on the board
GND: C4.2, Q1.1 (E2), Q11.2 (B1), R1.2, R8.2, R10.2, R14.2, U1.11, U3.3 (+); also elsewhere on the board
IREF_A: R20.1; also elsewhere on the board
unnamed: C4.1, R1.1, R3.2, U1.16
unnamed: C10.2, R22.1, U3.1
unnamed: Q1.2 (B2), Q1.3 (C1)
unnamed: Q2.1 (B2), Q2.2 (B1), Q2.6 (C2), Q4.5 (E2)
unnamed: Q2.3 (C1), Q4.4 (E1)
unnamed: Q3.1 (B2), Q3.2 (B1), Q3.6 (C2), Q5.5 (E2)
unnamed: Q3.3 (C1), Q5.4 (E1)
unnamed: Q4.1 (B2), Q4.2 (B1), Q4.3 (C1), U1.1
unnamed: Q5.6 (C2), U1.2
unnamed: C10.1, Q11.3 (C1), R20.2, U3.2 (-)
unnamed: Q11.4 (E1), Q11.5 (E2), R22.2
unnamed: Q5.1 (B2), Q5.2 (B1), Q5.3 (C1), Q11.6 (C2)
unnamed: U1.13, U3.10 (+)
unnamed: R4.1, R5.2, U3.9 (-)
unnamed: R10.1, R12.1, U3.12 (+)
unnamed: R14.1, R15.2, R17.1, U3.13 (-)
unnamed: U1.12, U5.2 (-)
SAWTOOTH_A: R4.2, U3.8; also elsewhere on the board
SYNC_A: Q1.5 (B1); also elsewhere on the board
TRIANGLE_A: R3.1, R5.1, R12.2, U3.6 (-), U3.7, U5.3 (+); also elsewhere on the board
VTH_A: R6.2, R8.1, U1.10, U1.15; also elsewhere on the board

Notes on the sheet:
CF_A = EXTERNAL 1000pF CAPACITOR to GND
VTH_A = 4V NOMINAL
VCO A
CROSSOVER COMPENSATION

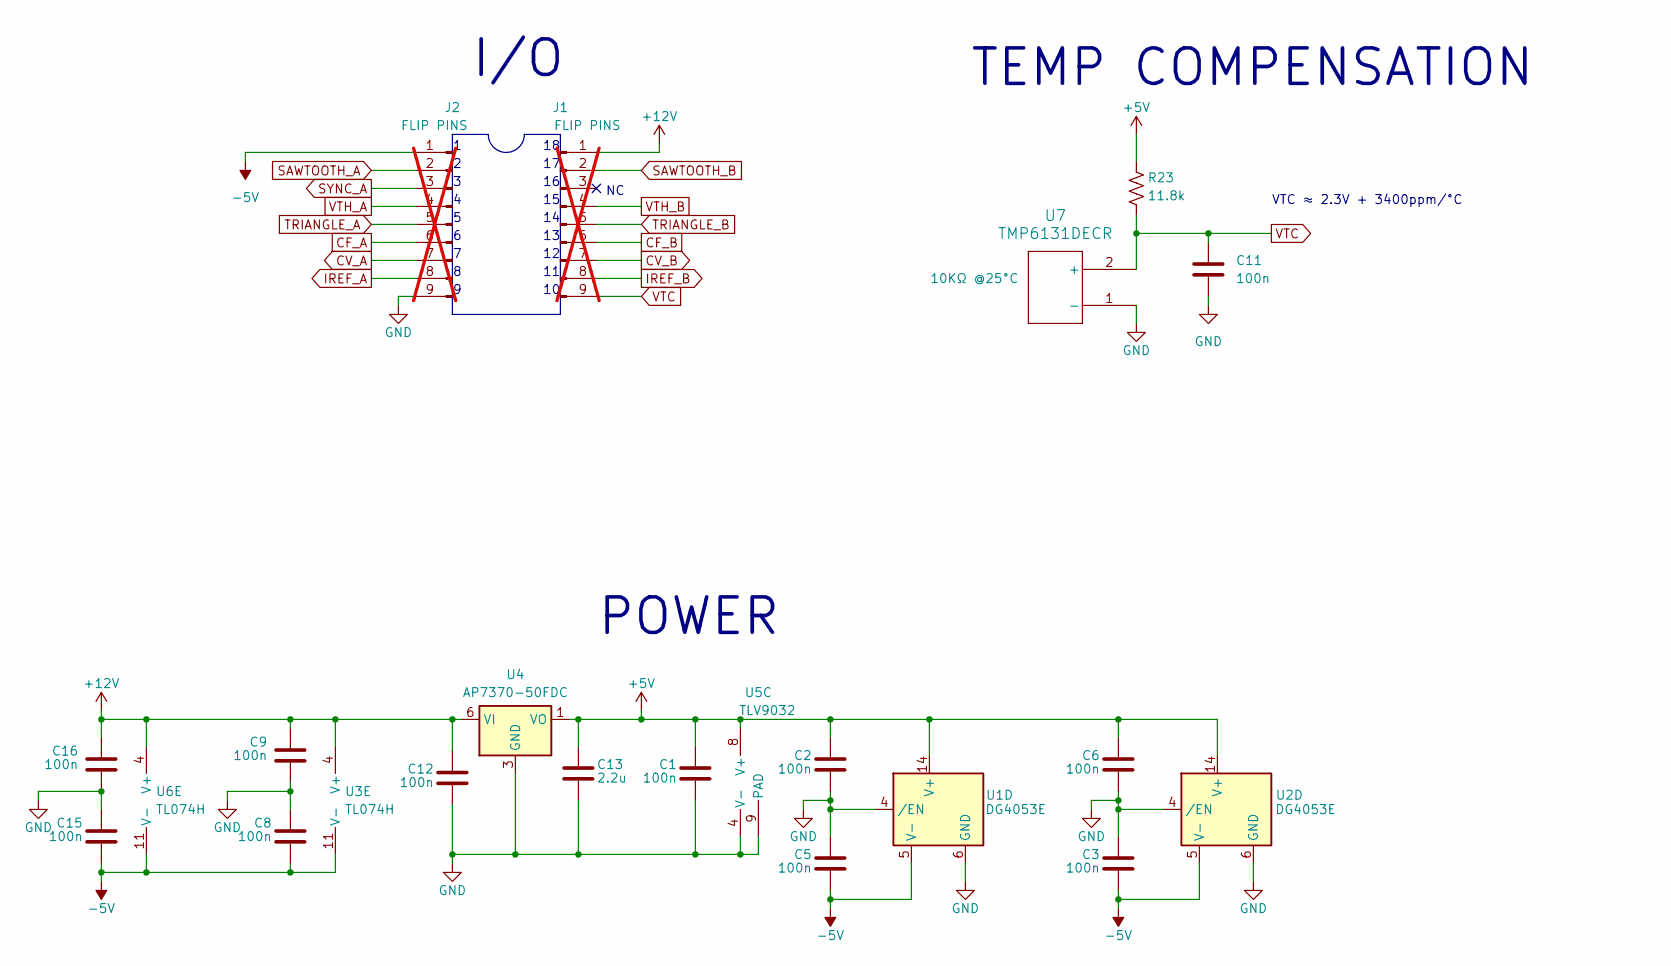
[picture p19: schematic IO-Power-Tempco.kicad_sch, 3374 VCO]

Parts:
C1, C2, C3, C5, C6, C8, C9, C11, C12, C15, C16: 100n; C_0201_0603Metric; Rating 25V; Tolerance 10%; Mfg PN 0201X104K250CT
C13: 2.2u; C_0402_1005Metric; Rating 25V; Tolerance 10%; Mfg PN GRM155R61E225KE11D
J1, J2: FLIP PINS; FLIP-PINS-FLOAT-09; Mfg PN FLIP-PINS-09; not fitted
R23: 11.8k; R_0201_0603Metric; Rating 0.05W; Tolerance 1%; Mfg PN AC0201FR-0711K8L
U1, U2: DG4053E; QFN_EEN-T1-GE4_VIS; Mfg PN DG4053EEN-T1-GE4
U3, U6: TL074H; SOT23_DYY_TEX-L; Mfg PN TL074HIDYYR
U4: AP7370-50FDC; DFN-6-1EP_2x2mm_P0.65mm_EP1.01x1.7mm; Mfg PN AP7370-50FDC-7
U5: TLV9032; WSON-8-1EP_2x2mm_P0.5mm_EP0.9x1.6mm; Mfg PN TLV9032DSGR
U7: TMP6131DECR; X1SON2_1XP65_TEX-L; Mfg PN TMP6131DECR

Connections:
+5V: C1.1, C2.1, C6.1, C13.1, R23.1, U1.14 (V+), U2.14 (V+), U4.1 (VO), U5.8 (V+); also elsewhere on the board
+12V: C9.1, C12.1, C16.1, J1.1, U3.4 (V+), U4.6 (VI), U6.4 (V+); also elsewhere on the board
-5V: C3.2, C5.2, C8.2, C15.2, J2.1, U1.5 (V-), U2.5 (V-), U3.11 (V-), U6.11 (V-)
CF_A: J2.6; also elsewhere on the board
CF_B: J1.6; also elsewhere on the board
CV_A: J2.7; also elsewhere on the board
CV_B: J1.7; also elsewhere on the board
GND: C1.2, C2.2, C3.1, C5.1, C6.2, C8.1, C9.2, C11.2, C12.2, C13.2, C15.1, C16.2, J2.9, U1.4 (/EN), U1.6 (GND), U2.4 (/EN), U2.6 (GND), U4.3 (GND), U4.7 (GND), U5.4 (V-), U5.9 (PAD), U7.1 (-); also elsewhere on the board
IREF_A: J2.8; also elsewhere on the board
IREF_B: J1.8; also elsewhere on the board
SAWTOOTH_A: J2.2; also elsewhere on the board
SAWTOOTH_B: J1.2; also elsewhere on the board
SYNC_A: J2.3; also elsewhere on the board
TRIANGLE_A: J2.5; also elsewhere on the board
TRIANGLE_B: J1.5; also elsewhere on the board
VTC: C11.1, J1.9, R23.2, U7.2 (+)
VTH_A: J2.4; also elsewhere on the board
VTH_B: J1.4; also elsewhere on the board

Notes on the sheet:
I/O
VTC ≈ 2.3V + 3400ppm/°C
TEMP COMPENSATION
POWER

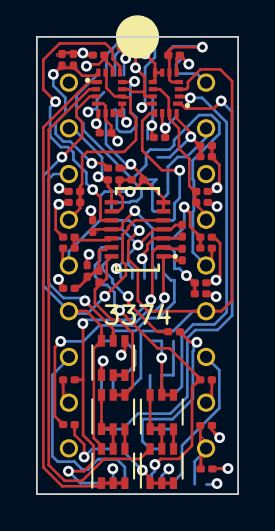
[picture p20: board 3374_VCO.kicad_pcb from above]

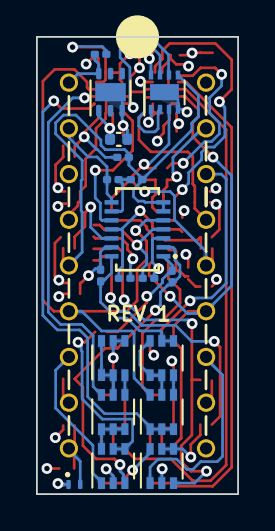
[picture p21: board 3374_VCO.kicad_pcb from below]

Board: 4 copper layers, 11.2 x 25.4 mm, 63 parts (21 on the bottom side), 55 nets.
